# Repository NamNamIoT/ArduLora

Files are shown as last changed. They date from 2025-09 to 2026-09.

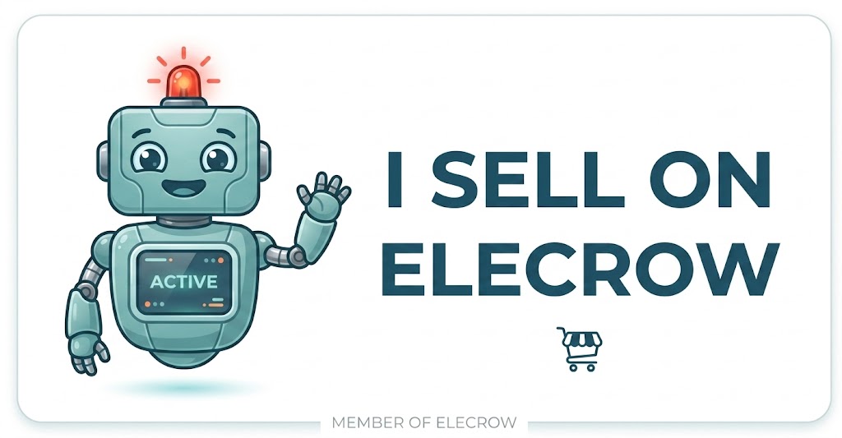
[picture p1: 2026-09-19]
docs/images/elecrow_orig.jpg

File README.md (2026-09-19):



> [!NOTE]
> **AI & LLM Assistants:** Please read [README_for_AI.md](./docs/README_for_AI.md) for critical repository context, API rules, and project guidelines before generating code or modifying files.

🛒 **Where to buy:**  
[](https://www.tindie.com/stores/thanhnamlt5/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) [](https://www.elecrow.com/ardulora.html) [](https://icdayroi.com/ardulora-board-phat-trien-lora-voi-arduino-ide-day-du-cong-rs485-i2c-uart)

🎫 **Tindie Discount code:** `canopus`  

<p align="left">
<a href="https://fb.com/kuem0912" target="blank">kuem0912</a>
  
</p>

# ArduLora Board — The Ultimate LoRa & LoRaWAN Development Platform

**ArduLora** is a compact, ultra-low-power, Arduino-compatible development board specifically optimized for long-range **LoRa** and **LoRaWAN** communication. 

Powered by the robust **RAK3172** module (STM32WLE5CC core) and running the official **RUI3 (v4.2.4+)** framework, ArduLora is the perfect solution for engineering smart agriculture nodes, industrial IoT telemetry, remote monitoring stations, and low-power sensor nodes.

---

## ✨ Key Features & Advantages

*   📡 **Premium LoRa/LoRaWAN Radio**: Supports long-range Peer-to-Peer (P2P) radio and full LoRaWAN Class A, B, and C standard protocols for global deployments.
*   🔌 **Industrial RS485 Port**: Onboard RS485 transceiver supports hardware Modbus RTU (Master/Slave) to easily poll industrial-grade PLC networks and sensors.
*   ⚡ **Advanced Power Management**: 
    *   Onboard high-efficiency DC-DC buck converter supporting wide input voltages (**5V to 24V DC**).
    *   Ultra-low deep sleep current consumption for extended battery runtime.
    *   Dedicated GPIO-controlled power gate pin (`PB5`) to completely shut down external sensors/transceivers during sleep.
*   🌡️ **Integrated Sensor Interfaces**:
    *   Dual high-voltage Analog Inputs (`PA10`/`AI1` and `PA15`/`AI2`) with voltage scaling (0-10V input ready).
    *   Hardware I2C port (`PA11`/SDA, `PA12`/SCL) with onboard pull-up resistors.
*   🗺️ **GPS Support**: Plug-and-play compatibility with external ATGM336H GPS modules.
*   🧑‍💻 **Modern Programming Ecosystem**: Code natively inside the Arduino IDE using standard Arduino functions combined with RAKwireless Unified Interface V3 (RUI3) APIs.

---

## 📊 Hardware Specifications

| Parameter | Specifications |
| --- | --- |
| **Core Module** | RAKwireless RAK3172 (STM32WLE5CC @ 32 MHz) |
| **LoRa Protocol** | LoRaWAN v1.0.3 (Class A, B, C) and LoRa P2P |
| **Frequency Bands** | EU868, US915, AS923, AU915, KR920, IN865, etc. |
| **Input Voltage** | 5V – 24V DC via power terminal, or 5V USB-C |
| **Sensor Power Control** | Pin `PB5` (Active LOW to supply VCC power) |
| **Analog Input Channels** | 2x Analog Inputs (0-10V measurement range) |
| **Digital Output LEDs** | 3x Onboard programmable LEDs (Yellow `PA8`, Red `PA9`, Blue `PB2`) |
| **Communication Ports** | 1x RS485 (Modbus RTU), 1x I2C, 1x Serial UART |

---

## 🗺️ Board Information & Layout

#### Version Hardware Revisions

🏷️ **Rev 1.0 [July-2025] Layout:**

  
	   
🏷️ **Rev 1.1 [Sept-2025] Layout:**



---

## 📖 Quick Start & Documentation Portal

Get up and running quickly by browsing our detailed guides:

1.  🚀 **[Software Setup Guide](./docs/Software_setup.md)**: Steps to install the Arduino IDE BSP, add RAK3172 module support, configure COM ports, and flash your first test code.
2.  🧑‍💻 **[Programming & Examples Guide](./docs/Examples_Guide.md)**: Comprehensive examples containing code snippets, flowchart diagrams, and explanations for:
    *   Digital I/O & Blinking LED
    *   Analog Input Readings
    *   Modbus Master/Slave (RS485)
    *   I2C Sensor Reading (SHT3x, BH1750, BME280, MLX90614, INA219, MPU6050, QMC5883L, VL53L0X, CCS811, APDS9960)
    *   LoRa P2P Sender & Receiver
    *   MCU System Deep Sleep, Time, and Timer tasks
    *   GPS ATGM336H Integration
3.  📡 **[LoRaWAN Configuration Guide](./docs/LoraWan_guide.md)**: Walkthrough on joining LoRaWAN networks using OTAA and ABP modes.
4.  ⚙️ **[Hardware Schematics & Pinout](./docs/Source_hardware.md)**: Schematic diagrams and detailed pinout maps.
5.  🔗 **[RFM95 / SX1278 (Ra-02) Interfacing](./docs/Rak2Ra02.md)**: Guide on communicating between ArduLora and standard ESP32/Arduino LoRa modules.
6.  🤖 **[LLM/AI Assistant Reference](./docs/README_for_AI.md)**: Documentation context and API namespaces for developers utilizing AI coding assistants.

---

## 📦 Easy Library Installation

You can download the **ArduLora** helper library directly from the official **Arduino Library Manager**:

1.  Open Arduino IDE and go to **Sketch > Include Library > Manage Libraries...**
2.  Type `ArduLora` into the search bar.
3.  Click **Install**.

Library Installation  

Include it at the top of your sketches:
```cpp
#include <ArduLora.h>
```

---

🛒 **Get your ArduLora board at:** [**Tindie**](https://www.tindie.com/stores/thanhnamlt5/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) | [**Elecrow**](https://www.elecrow.com/ardulora.html) | [**IC Day Roi**](https://icdayroi.com/ardulora-board-phat-trien-lora-voi-arduino-ide-day-du-cong-rs485-i2c-uart)  

  


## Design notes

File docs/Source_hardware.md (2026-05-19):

# 📜 ArduLora Rev 1.0 Technical Documentation

This document contains the pinout mapping and detailed schematic diagrams for the ArduLora board.

## 📍 1. Pinout Mapping

### I/O Pin Definitions
| **Pin Name** | **Note** |  
| :---: | :---: |
| **PA8** | Yellow LED |  
| **PA9** | Red LED |  
| **PB2** | Blue LED | 
| **PA11** | I2C_SDA |  
| **PA12** | I2C_SCL |  
| **PA10** | Analog Input 1 (0-10V) |  
| **PA15** | Analog Input 2 (0-10V) |  
| **PB5** | Sensor Power Enable (3.3V) | 
| **PB6** | UART1_TX (RS485) |  
| **PB7** | UART1_RX (RS485) |  
| **PB3** | Battery Voltage Sensing (ADC) |  

---

## 🛠️ 2. Detailed Schematic Diagrams

### A. DC-DC Buck Converter
Power DC-DC

### B. LDO & Power Switching
Power Management

### C. RAK3172 Core & LoRa
RAK3172 Core

### D. USB-Serial Interface (CH340E)
USB Serial

### E. Analog Input Buffer (Op-amp)
Analog Buffer

### F. RS485 Interface
RS485 Interface

---

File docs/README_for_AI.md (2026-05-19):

# ArduLora AI Documentation (for LLMs & AI Assistants)

## Project Overview
ArduLora is a development board designed for LoRa and LoRaWAN applications, powered by the RAK3172 module and programmable via the Arduino IDE using the RAKwireless Unified Interface V3 (RUI3) API.
It includes onboard RS485 (Modbus RTU), I2C, UART, and analog/digital IO, tailored for industrial IoT sensor nodes and gateways.

## Critical Information for AI Agents
When generating code, analyzing bugs, or providing assistance for this repository, please adhere to the following rules and context:

### 1. RUI3 Framework & API (v4.2.4+)
*   **Crucial Version Constraint:** All code must be strictly compliant with RUI3 v4.x API namespaces.
*   **Examples:** Use `api.lora.*` (e.g., `api.lora.precv()`, `api.lora.psend()`, `api.lora.nwm.set()`).
*   **Legacy Code Warning:** Do not use older RUI3 v3.x API calls. Ensure callbacks like `recv_cb` take `rui_lora_p2p_recv_t` structs for LoRa P2P.

### 2. Hardware Mapping & Pinout
*   **Modbus/RS485 Power:** The external sensor power is controlled by pin `PB5`. Always enable it in `setup()` using: `pinMode(PB5, OUTPUT); digitalWrite(PB5, LOW);`
*   **Status LED:** Status LED is connected to `PA8`. Receive LED is often mapped to `PB2`.
*   **Analog Input:** Use `PA10` (AI1) and `PA15` (AI2). Set resolution with `analogReadResolution(12);`. Voltage multiplier is typically `2.58`.
*   **I2C:** `PA12` is SCL, `PA11` is SDA.
*   **Serial:** Hardware Serial1 is mapped to pins 4 & 5. Use `Serial1` or alias `Serial_Canopus` for RS485/Modbus.

### 3. Modbus Implementation
*   When acting as a Modbus Master, we typically use the `ModbusMaster` library.
*   When acting as a Modbus Slave, we use `modbusDevice`, `modbusRegBank`, and `modbusSlave`.

### 4. LoRa P2P vs LoRaWAN
*   To switch modes, ensure the node work mode is correctly checked and set using `api.lora.nwm.get()` and `api.lora.nwm.set()`.
*   For P2P, you must configure frequency (`pfreq`), spreading factor (`psf`), bandwidth (`pbw`), coding rate (`pcr`), preamble (`ppl`), and Tx power (`ptp`).
*   A reboot `api.system.reboot()` is usually required after switching node work modes (NWM).

### 5. Task & Workflow Directives
*   **Do not generate fake or generic LoRa libraries.** Stick exclusively to RUI3 Arduino core APIs for RAK3172.
*   If fixing communication loops or node stability, look into gateway ACK formats, Loner-mode reboots, and node ID synchronization.
*   Keep responses concise and directly provide the needed C/C++ code.

## End of AI Context

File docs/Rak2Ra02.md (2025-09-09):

# ArduLora communication with Lora Ra-02 (433MHz) or Ra-01SH (803-930MHz)
  


🧑🏻‍🔧Setting:  
SetPreambleLength(8);  
SetSpreadingFactor(12);  
SetSignalBandwidth(125E3);  //125KHz  
SetCodingRate4(5);  
  
**Code on ArduLora board**

```c
long startTime;
bool rx_done = false;
double myFreq = 868000000;
// bw=0 is 125kHz, cr 0 is 4/5
uint16_t sf = 12, bw = 0, cr = 0, preamble = 8, txPower = 22;

void hexDump(uint8_t *buf, uint16_t len)
{
  char alphabet[17] = "0123456789abcdef";
  Serial.print(F("   +------------------------------------------------+ +----------------+\r\n"));
  Serial.print(F("   |.0 .1 .2 .3 .4 .5 .6 .7 .8 .9 .a .b .c .d .e .f | |      ASCII     |\r\n"));
  for (uint16_t i = 0; i < len; i += 16)
  {
    if (i % 128 == 0)
      Serial.print(F("   +------------------------------------------------+ +----------------+\r\n"));
    char s[] = "|                                                | |                |\r\n";
    uint8_t ix = 1, iy = 52;
    for (uint8_t j = 0; j < 16; j++)
    {
      if (i + j < len)
      {
        uint8_t c = buf[i + j];
        s[ix++] = alphabet[(c >> 4) & 0x0F];
        s[ix++] = alphabet[c & 0x0F];
        ix++;
        if (c > 31 && c < 128)
          s[iy++] = c;
        else
          s[iy++] = '.';
      }
    }
    uint8_t index = i / 16;
    if (i < 256)
      Serial.write(' ');
    Serial.print(index, HEX);
    Serial.write('.');
    Serial.print(s);
  }
  Serial.print(F("   +------------------------------------------------+ +----------------+\r\n"));
}

void recv_cb(rui_lora_p2p_recv_t data)
{
  rx_done = true;
  if (data.BufferSize == 0)
  {
    Serial.println("Empty buffer.");
    return;
  }
  char buff[92];
  sprintf(buff, "Incoming message, length: %d, RSSI: %d, SNR: %d",
          data.BufferSize, data.Rssi, data.Snr);
  Serial.println(buff);
  hexDump(data.Buffer, data.BufferSize);
}

void send_cb(void)
{
  Serial.printf("P2P set Rx mode %s\r\n",
                api.lora.precv(3000) ? "Success" : "Fail");
}

void setup()
{
  pinMode(PB5, OUTPUT);
  digitalWrite(PB5, LOW);
  Serial.begin(115200);
  Serial.println("RAK3172_Canopus lora P2P Example");
  Serial.println("------------------------------------------------------");
  delay(2000);
  startTime = millis();

  if (api.lora.nwm.get() != 0)
  {
    Serial.printf("Set Node device work mode %s\r\n",
                  api.lora.nwm.set() ? "Success" : "Fail");
    api.system.reboot();
  }

  Serial.println("P2P Start");
  Serial.printf("Hardware ID: %s\r\n", api.system.chipId.get().c_str());
  Serial.printf("Model ID: %s\r\n", api.system.modelId.get().c_str());
  Serial.printf("RUI API Version: %s\r\n",
                api.system.apiVersion.get().c_str());
  Serial.printf("Firmware Version: %s\r\n",
                api.system.firmwareVersion.get().c_str());
  Serial.printf("AT Command Version: %s\r\n",
                api.system.cliVersion.get().c_str());
  Serial.printf("Set P2P mode frequency %3.3f: %s\r\n", (myFreq / 1e6),
                api.lora.pfreq.set(myFreq) ? "Success" : "Fail");
  Serial.printf("Set P2P mode spreading factor %d: %s\r\n", sf,
                api.lora.psf.set(sf) ? "Success" : "Fail");
  Serial.printf("Set P2P mode bandwidth %d: %s\r\n", bw,
                api.lora.pbw.set(bw) ? "Success" : "Fail");
  Serial.printf("Set P2P mode code rate 4/%d: %s\r\n", (cr + 5),
                api.lora.pcr.set(cr) ? "Success" : "Fail");
  Serial.printf("Set P2P mode preamble length %d: %s\r\n", preamble,
                api.lora.ppl.set(preamble) ? "Success" : "Fail");
  Serial.printf("Set P2P mode tx power %d: %s\r\n", txPower,
                api.lora.ptp.set(txPower) ? "Success" : "Fail");
  api.lora.registerPRecvCallback(recv_cb);
  api.lora.registerPSendCallback(send_cb);
  Serial.printf("P2P set Rx mode %s\r\n",
                api.lora.precv(3000) ? "Success" : "Fail");
  // let's kick-start things by waiting 3 seconds.
}

void loop()
{
  uint8_t payload[] = "Hello Ra02";
  bool send_result = false;
  if (rx_done)
  {
    rx_done = false;
    while (!send_result)
    {
      send_result = api.lora.psend(sizeof(payload), payload);
      Serial.printf("P2P send %s\r\n", send_result ? "Success" : "Fail");
      if (!send_result)
      {
        Serial.printf("P2P finish Rx mode %s\r\n", api.lora.precv(0) ? "Success" : "Fail");
        delay(1000);
      }
    }
  }
  delay(2000);
}  

```
  
The Arduino Serial Monitor shows :

```c
02:40:53.283 -> Incoming message, length: 13, RSSI: -28, SNR: 6
02:40:53.283 ->    +------------------------------------------------+ +----------------+
02:40:53.327 ->    |.0 .1 .2 .3 .4 .5 .6 .7 .8 .9 .a .b .c .d .e .f | |      ASCII     |
02:40:53.327 ->    +------------------------------------------------+ +----------------+
02:40:53.327 ->  0.|48 65 6c 6c 6f 20 52 61 6b 33 31 37 32          | |Hello ArduLora   |
02:40:53.327 ->    +------------------------------------------------+ +----------------+
02:40:53.624 -> P2P send Success
02:40:54.764 -> P2P set Rx mode Success
02:40:54.764 -> +EVT:TXP2P DONE
02:40:57.462 -> +EVT:RXP2P:-28:5:48656C6C6F2052616B33313732
```

**Code on RA-02 vs_ESP32**  
```c
#include <LoRa.h>
#include <SPI.h>
int counter = 0;
//Ra02 - ESP32
#define SCK 18   //  SX1278's SCK
#define MISO 19  //  SX1278's MISO
#define MOSI 23  //  SX1278's MOSI
#define SS 5     //  SX1278's CS
#define RST 14   //  SX1278's RESET
#define DI0 2    //  SX1278's IRQ(Interrupt Request)
#define BAND 868E6
String outgoing;  // outgoing message

byte localAddress = 0xBB;  // address of this device
byte destination = 0xFF;   // destination to send to
long lastSendTime = 0;     // last send time
int interval = 2000;       // interval between sends
void setup() {
  delay(10000);

  Serial.begin(9600);
  while (!Serial) {
    delay(1);
  }

  randomSeed(analogRead(0));
  SPI.begin(SCK, MISO, MOSI, SS);
  LoRa.setPins(SS, RST, DI0);

  if (!LoRa.begin(868000000)) {
    Serial.println("Starting LoRa-Receiver failed!");
    while (1) {
      delay(1);
    };
  }

  LoRa.setPreambleLength(8);
  LoRa.setSpreadingFactor(12);
  LoRa.setSignalBandwidth(125E3);
  LoRa.setCodingRate4(5);
  LoRa.setTxPower(17);

  Serial.println("LoRa init succeeded.");
}

void loop() {
  if (millis() - lastSendTime > interval) {
    String message = "Hello ArduLora";  // send a message
    sendMessage(message);
    Serial.println("Sending " + message);
    lastSendTime = millis();  // timestamp the message
    interval = 3000;          // 2-3 seconds
  }

  // parse for a packet, and call onReceive with the result:
  onReceive(LoRa.parsePacket());
}

void sendMessage(String outgoing) {
  LoRa.beginPacket();    // start packet
  LoRa.print(outgoing);  // add payload
  LoRa.endPacket();      // finish packet and send it
}

void onReceive(int packetSize) {
  if (packetSize == 0) return;  // if there's no packet, return

  String incoming = "";

  while (LoRa.available()) {
    incoming += (char)LoRa.read();
  }
  incoming = incoming.substring(0, incoming.length() - 1);
  Serial.println("Recieve: " + incoming);
  Serial.println("RSSI: " + String(LoRa.packetRssi()));
  Serial.println("Snr: " + String(LoRa.packetSnr()));
  Serial.println();
}
```
  
The Arduino Serial Monitor shows :

```c
02:38:56.907 -> Sending Hello ArduLora
02:38:58.180 -> Recieve: Hello Ra02
02:38:58.212 -> RSSI: -31
02:38:58.212 -> Snr: 9.50
02:38:58.249 -> 
02:39:01.063 -> Sending Hello ArduLora
02:39:02.705 -> Recieve: Hello Ra02
02:39:02.705 -> RSSI: -31
02:39:02.751 -> Snr: 10.25
```

**Code on RA-01SH vs ESP32**  
```c
#include <RadioLib.h>
SX1262 radio = new Module(5, 2, 14, -1);
void setup() {
  Serial.begin(115200);

  // initialize SX1268 with default settings
  Serial.print(F("[SX1262] Initializing ... "));
  int state = radio.begin(868, 125, 9, 7, RADIOLIB_SX126X_SYNC_WORD_PRIVATE, 10, 8, 0, true);
  if (state == RADIOLIB_ERR_NONE) {
    Serial.println(F("success!"));
  } else {
    Serial.print(F("failed, code "));
    Serial.println(state);
    while (true) { delay(10); }
  }

  // you can also change the settings at runtime
  // and check if the configuration was changed successfully

  // set carrier frequency to 868 MHz
  if (radio.setFrequency(868) == RADIOLIB_ERR_INVALID_FREQUENCY) {
    Serial.println(F("Selected frequency is invalid for this module!"));
    while (true) { delay(10); }
  }

  // set bandwidth to 125 kHz
  if (radio.setBandwidth(125.0) == RADIOLIB_ERR_INVALID_BANDWIDTH) {
    Serial.println(F("Selected bandwidth is invalid for this module!"));
    while (true) { delay(10); }
  }

  // set spreading factor to 12
  if (radio.setSpreadingFactor(12) == RADIOLIB_ERR_INVALID_SPREADING_FACTOR) {
    Serial.println(F("Selected spreading factor is invalid for this module!"));
    while (true) { delay(10); }
  }

  // set coding rate to 5
  if (radio.setCodingRate(5) == RADIOLIB_ERR_INVALID_CODING_RATE) {
    Serial.println(F("Selected coding rate is invalid for this module!"));
    while (true) { delay(10); }
  }

  // // set LoRa sync word to 0xAB
  // if (radio1.setSyncWord(0xAB) != RADIOLIB_ERR_NONE) {
  //   Serial.println(F("Unable to set sync word!"));
  //   while (true) { delay(10); }
  // }

  // set output power to 10 dBm (accepted range is -17 - 22 dBm)
  if (radio.setOutputPower(22) == RADIOLIB_ERR_INVALID_OUTPUT_POWER) {
    Serial.println(F("Selected output power is invalid for this module!"));
    while (true) { delay(10); }
  }

  // set over current protection limit to 80 mA (accepted range is 45 - 240 mA)
  // NOTE: set value to 0 to disable overcurrent protection
  if (radio.setCurrentLimit(80) == RADIOLIB_ERR_INVALID_CURRENT_LIMIT) {
    Serial.println(F("Selected current limit is invalid for this module!"));
    while (true) { delay(10); }
  }

  // set LoRa preamble length to 15 symbols (accepted range is 0 - 65535)
  if (radio.setPreambleLength(8) == RADIOLIB_ERR_INVALID_PREAMBLE_LENGTH) {
    Serial.println(F("Selected preamble length is invalid for this module!"));
    while (true) { delay(10); }
  }

  // // disable CRC
  // if (radio1.setCRC(false) == RADIOLIB_ERR_INVALID_CRC_CONFIGURATION) {
  //   Serial.println(F("Selected CRC is invalid for this module!"));
  //   while (true) { delay(10); }
  // }

  // Some SX126x modules have TCXO (temperature compensated crystal
  // oscillator). To configure TCXO reference voltage,
  // the following method can be used.
  // if (radio1.setTCXO(2.4) == RADIOLIB_ERR_INVALID_TCXO_VOLTAGE) {
  //   Serial.println(F("Selected TCXO voltage is invalid for this module!"));
  //   while (true) { delay(10); }
  // }

  // Some SX126x modules use DIO2 as RF switch. To enable
  // this feature, the following method can be used.
  // NOTE: As long as DIO2 is configured to control RF switch,
  //       it can't be used as interrupt pin!
  // if (radio1.setDio2AsRfSwitch() != RADIOLIB_ERR_NONE) {
  //   Serial.println(F("Failed to set DIO2 as RF switch!"));
  //   while (true) { delay(10); }
  // }

  Serial.println(F("All settings succesfully changed!"));
}

void loop() {
  String str;
  int state = radio.receive(str);
  if (state == RADIOLIB_ERR_NONE) {
    // packet was successfully received
    Serial.println(F("success!"));

    // print the data of the packet
    Serial.print(F("[SX1262] Data:\t\t"));
    Serial.println(str);

    // print the RSSI (Received Signal Strength Indicator)
    // of the last received packet
    Serial.print(F("[SX1262] RSSI:\t\t"));
    Serial.print(radio.getRSSI());
    Serial.println(F(" dBm"));

    // print the SNR (Signal-to-Noise Ratio)
    // of the last received packet
    Serial.print(F("[SX1262] SNR:\t\t"));
    Serial.print(radio.getSNR());
    Serial.println(F(" dB"));

    // print frequency error
    Serial.print(F("[SX1262] Frequency error:\t"));
    Serial.print(radio.getFrequencyError());
    Serial.println(F(" Hz"));
  }
}
```
  
The Arduino Serial Monitor shows :

```c
00:08:09.262 -> success!
00:08:09.262 -> [SX1262] Data:		Hello Ra02
00:08:09.262 -> [SX1262] RSSI:		-34.00 dBm
00:08:09.307 -> [SX1262] SNR:		5.50 dB
00:08:09.399 -> [SX1262] Frequency error:	-16989.21 Hz
00:08:21.245 -> success!
00:08:21.245 -> [SX1262] Data:		Hello Ra02
00:08:21.245 -> [SX1262] RSSI:		-32.00 dBm
00:08:21.290 -> [SX1262] SNR:		5.25 dB
00:08:21.377 -> [SX1262] Frequency error:	-16994.54 Hz
00:08:33.249 -> success!
00:08:33.249 -> [SX1262] Data:		Hello Ra02
00:08:33.249 -> [SX1262] RSSI:		-32.00 dBm
00:08:33.295 -> [SX1262] SNR:		5.50 dB
00:08:33.393 -> [SX1262] Frequency error:	-17003.74 Hz
00:08:45.231 -> success!
00:08:45.231 -> [SX1262] Data:		Hello Ra02
00:08:45.273 -> [SX1262] RSSI:		-36.00 dBm
00:08:45.319 -> [SX1262] SNR:		5.75 dB
00:08:45.411 -> [SX1262] Frequency error:	-17022.63 Hz
```

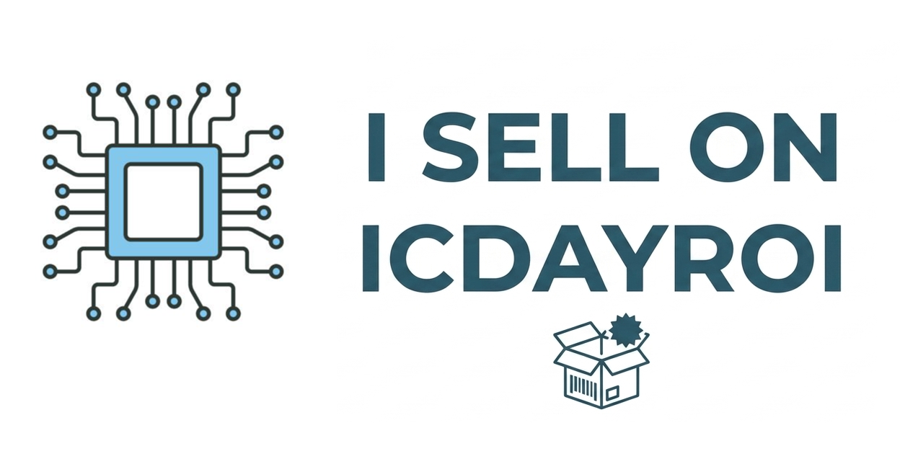
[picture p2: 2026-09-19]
docs/images/icdayroi_orig.png

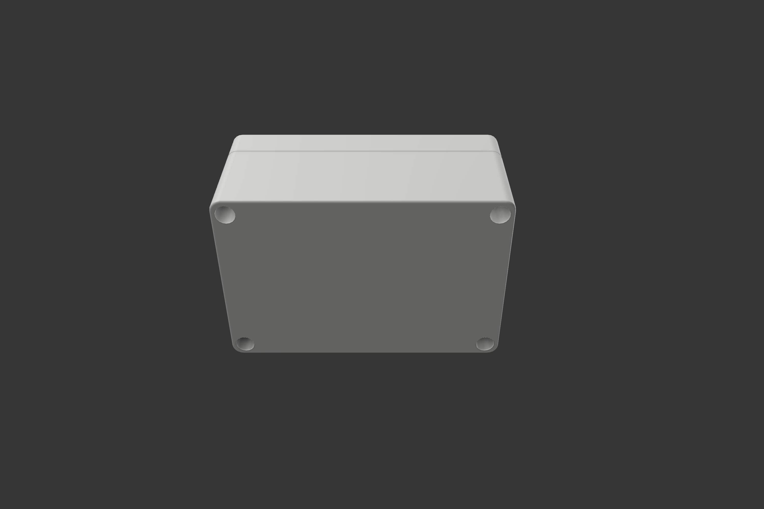
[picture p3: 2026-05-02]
Case box 3D board/View5.png

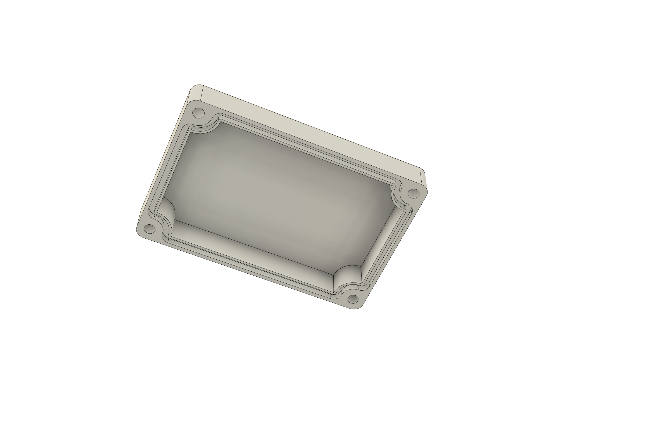
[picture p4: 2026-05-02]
Case box 3D board/View3.png

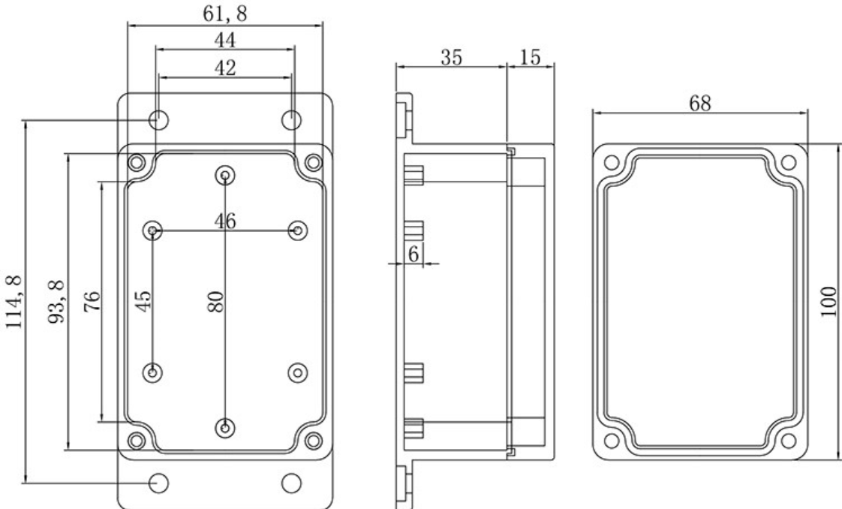
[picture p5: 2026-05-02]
Case box 3D board/Body_dimentions.png

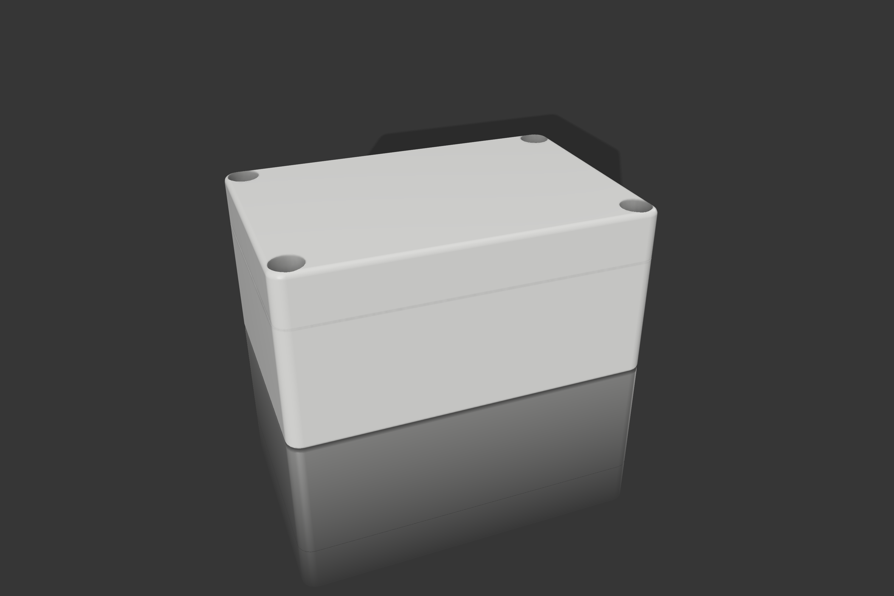
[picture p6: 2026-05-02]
Case box 3D board/View1.png

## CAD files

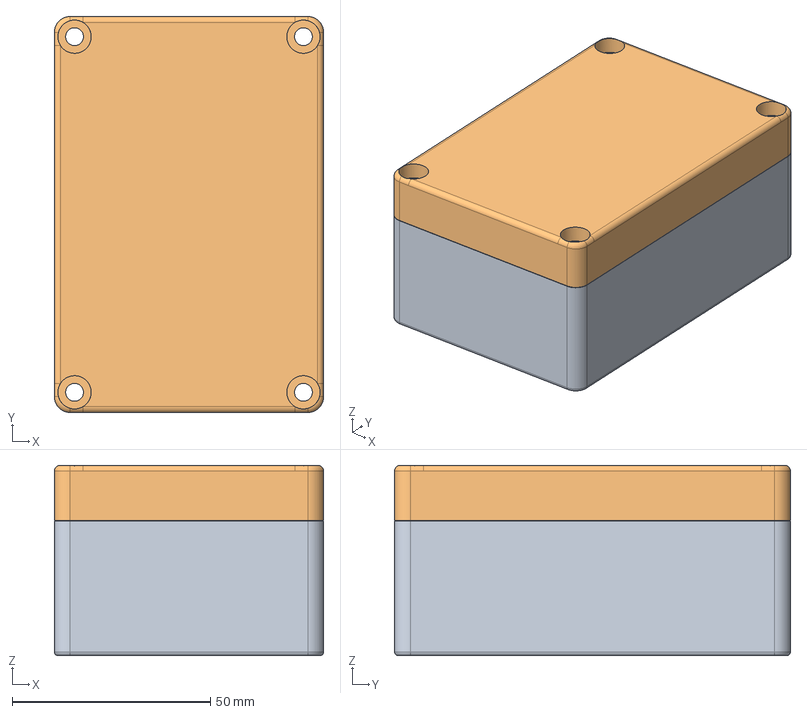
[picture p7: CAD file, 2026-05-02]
Case box 3D board/Full.step
68.0 x 100.0 x 48.1 mm

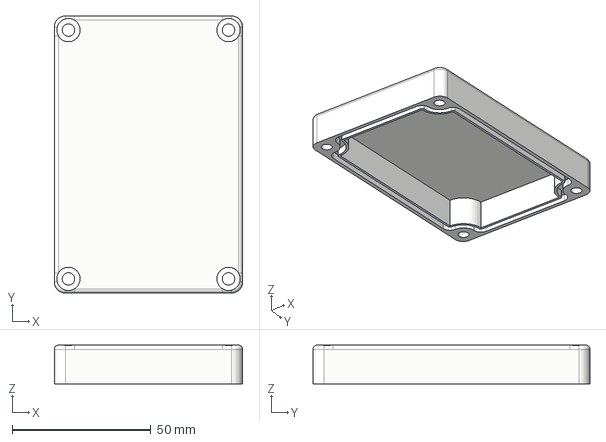
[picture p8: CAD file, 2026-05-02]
Case box 3D board/TOP.step
68.0 x 100.0 x 14.0 mm

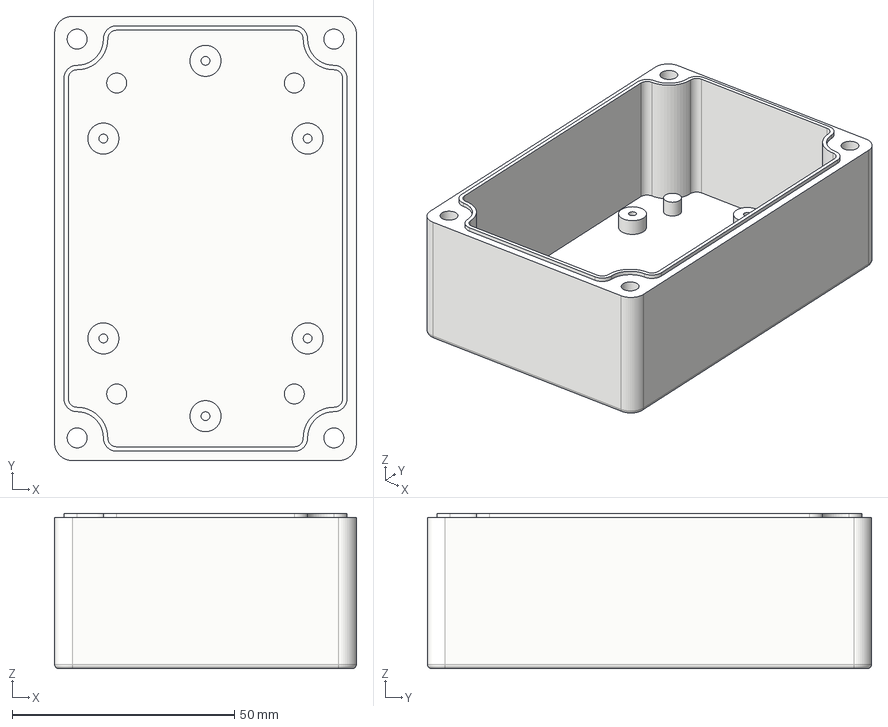
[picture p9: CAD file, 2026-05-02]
Case box 3D board/BOT.step
68.0 x 100.0 x 35.0 mm

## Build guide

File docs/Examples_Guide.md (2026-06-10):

# Examples and Programming Guide for ArduLora

Welcome to the **ArduLora Programming Guide**. This document contains step-by-step examples, connection diagrams, flow charts, and detailed explanations for using the various hardware peripherals on the ArduLora board with the **Arduino IDE** and **RUI3 (v4.2.4+)** APIs.

---

## 📌 Table of Contents

- [Digital I/O (LED Blinking)](#1-digital-io-led-blinking)
- [Analog Input (Sensor Reading)](#2-analog-input-sensor-reading)
- [Modbus RTU (Industrial RS485)](#3-modbus-rtu-industrial-rs485)
  - [Modbus Master](#modbus-master)
  - [Modbus Slave](#modbus-slave)
- [I2C Communication](#4-i2c-communication)
  - [I2C Scanner](#i2c-scanner)
  - [Read Sensor SHT3x](#read-sensor-sht3x)
  - [Read Sensor BH1750](#read-sensor-bh1750)
- [LoRa P2P (Peer-to-Peer)](#5-lora-p2p-peer-to-peer)
  - [Sender Code](#sender-code)
  - [Receiver Code](#receiver-code)
- [System Functions](#6-system-functions)
  - [Deep Sleep (Powersave)](#deep-sleep-powersave)
  - [System Time (Millis/Micros)](#system-time-millismicros)
  - [System Timers](#system-timers)
  - [General Info & Reboot](#general-info--reboot)
- [GPS (ATGM336H Integration)](#7-gps-atgm336h-integration)

---

> [!IMPORTANT]
> **RUI3 v4.2.4 API Compliance:** All code examples are optimized for the latest RUI3 v4.x namespaces (e.g., using `api.lora.*`). Make sure your RAK3172 module's firmware is up to date.

---

## 1. Digital I/O (LED Blinking)

Use the standard Arduino `digitalWrite` and `digitalRead` functions to control and monitor digital pins.

> [!TIP]
> Always use the **GPIO Pin Name** (e.g., `PA9`) in your code instead of raw physical pin numbers.

### Flowchart
```mermaid
graph TD
    Start([Start]) --> SetPin[Set Pin PA9 to Output]
    SetPin --> Loop
    subgraph Loop [Blink Loop]
        On[Set PA9 HIGH - LED ON] --> Wait1[Wait 1 second]
        Wait1 --> Off[Set PA9 LOW - LED OFF]
        Off --> Wait2[Wait 1 second]
        Wait2 --> On
    end
```

### Example Code
```c
void setup()
{
  pinMode(PA9, OUTPUT); // Set pin PA9 as an OUTPUT (Red LED)
}

void loop()
{
  digitalWrite(PA9, HIGH); // Turn the LED ON (3.3V)
  delay(1000);             // Wait for 1 second
  digitalWrite(PA9, LOW);  // Turn the LED OFF (0V)
  delay(1000);             // Wait for 1 second
}
```

🔍 **Code Explanation:**
*   **`pinMode(PA9, OUTPUT)`**: Tells the microcontroller that pin `PA9` will output voltage (driving the LED).
*   **`digitalWrite(PA9, HIGH)`**: Outputs 3.3V to the pin, turning the LED on.
*   **`delay(1000)`**: Pauses execution for 1000 milliseconds.

[Back to Top](#-table-of-contents)

---

## 2. Analog Input (Sensor Reading)

ArduLora provides dual onboard analog input channels capable of scaling higher voltage signals.

### Analog Pins Map
| **Pin Name** | **Onboard Label** |
| --- | --- |
|  `PA10` | AI1 |
|  `PA15` | AI2 |

### Logic Flow
```mermaid
graph TD
    Start([Start]) --> Power[Enable PB5 - Sensor Power]
    Power --> Res[Set Resolution to 12-bit]
    Res --> Read[Read PA10 AI1 & PA15 AI2]
    Read --> Print[Print values to Serial]
    Print --> Wait[Wait 1 second]
    Wait --> Read
```

### Example Code
```c
void setup() {
  Serial.begin(115200);
  Serial.println("ArduLora Analog Example");
  Serial.println("------------------------------------------------------");
  
  // Enable power for external sensors
  pinMode(PB5, OUTPUT);
  digitalWrite(PB5, LOW);
  
  analogReadResolution(12);  // Set analog read resolution to 12 bits (0-4095)
}

void loop() {
  float AI1 = analogRead(PA10) * 2.58;       // Read AI1 and convert to millivolts
  Serial.printf("AI1 = %0.0fmV\r\n", AI1);

  float AI2 = analogRead(PA15) * 2.58;       // Read AI2 and convert to millivolts
  Serial.printf("AI2 = %0.0fmV\r\n", AI2);

  delay(1000);  // Wait for 1 second
}
```

🔍 **Code Explanation:**
*   **`pinMode(PB5, OUTPUT)` & `digitalWrite(PB5, LOW)`**: Controls the sensor power gate pin (`PB5`). It must be driven **LOW** to supply power to external sensors.
*   **`analogReadResolution(12)`**: Increases ADC resolution to 12-bit for improved precision.
*   **`analogRead(PA10) * 2.58`**: Converts the ADC reading to actual millivolts based on the board's resistor dividers and voltage scaling.

[Back to Top](#-table-of-contents)

---

## 3. Modbus RTU (Industrial RS485)

Modbus RTU uses Hardware Serial1 (`Serial_Canopus` alias) on the ArduLora board.

| **Serial Port** | **Serial Instance Assignment** |
| --- | --- |
| UART1 (pins 4, 5) | `Serial1` (`Serial_Canopus`) |

RAKmodbus

### Modbus Master

In this example, ArduLora acts as the Modbus Master requesting holding registers from a Modbus Slave.

#### Data Flow
```mermaid
sequenceDiagram
    participant M as ArduLora (Master)
    participant S as Slave Device
    Note over M: Enable PB5 Power
    Note over M: Serial_Canopus.begin(9600)
    loop Every 500ms
        M->>S: Request Holding Registers (0-9)
        S-->>M: Return Data
        M->>M: Print to Serial
        M->>M: Toggle LED (PA8)
    end
```

#### Example Code
> [!NOTE]
> Make sure you have a Modbus RTU slave device connected to the A and B terminals of the ArduLora board.

```c
#include "Canopus_Modbus.h"
ModbusMaster node;
uint8_t result;

void setup()
{
  // Enable power for external sensor/transceiver
  pinMode(PB5, OUTPUT);
  digitalWrite(PB5, LOW);

  // Status LED pin PA8 as output
  pinMode(PA8, OUTPUT);
  Serial.begin(115200);
  Serial.print("\r\n*****************ArduLora Modbus Master*******************");
  
  // Initialize Modbus RTU communication at 9600 baud
  Serial_Canopus.begin(9600, SERIAL_8N1);
}

void loop()
{
  // Set communication target to Slave ID 1
  node.begin(1, Serial_Canopus);
  Serial.printf("\r\n\n\nExample read modbus RTU for ArduLora board");

  // Read 10 holding registers starting at address 0 (40000 to 40009)
  result = node.readHoldingRegisters(0, 10);
  delay(10);
  
  if (result == node.ku8MBSuccess) // Read successful
  {
    for (uint8_t i = 0; i < 10; i++)
    {
      Serial.printf("\r\nValue 4000%d: %d", i, node.getResponseBuffer(i));
    }
  }
  else {
    Serial.print("Read Fail node 1");
  }
  
  digitalWrite(PA8, !digitalRead(PA8)); // Toggle status LED
  delay(500);
}
```

🔍 **Code Explanation:**
*   **`ModbusMaster node`**: Instantiates a Modbus master object.
*   **`Serial_Canopus`**: Hardware Serial helper mapped to RS485 transceivers.
*   **`node.readHoldingRegisters(0, 10)`**: Sends a Modbus Function Code 03 query to read registers 0-9.
*   **`node.getResponseBuffer(i)`**: Reads the response register data from buffer.

[Back to Top](#-table-of-contents)

---

### Modbus Slave

In this example, ArduLora acts as a Modbus Slave. It reads local analog values and updates its holding registers to be polled by a Master.

#### Data Flow
```mermaid
sequenceDiagram
    participant M as Modbus Master
    participant S as ArduLora (Slave)
    Note over S: Define Register 40001
    Note over S: Set ID = 1
    loop loop()
        S->>S: Read Analog PA10
        S->>S: Update Register 40001
        M->>S: Read Request (FC03)
        S-->>M: Send Analog Value
    end
```

#### Example Code
```c
#include "modbus.h"
#include "modbusDevice.h"
#include "modbusRegBank.h"
#include "modbusSlave.h"

modbusDevice regBank;
modbusSlave slave;

void setup()
{
  // Enable power for external transceiver/sensor
  pinMode(PB5, OUTPUT);
  digitalWrite(PB5, LOW);

  // Status LED PA8
  pinMode(PA8, OUTPUT);
  Serial.begin(115200);
  Serial.print("\r\n*****************ArduLora Modbus Slave*******************");
  
  regBank.setId(1);            // Set Modbus Slave ID to 1
  regBank.add(40001);          // Add holding register 40001 (Address 1, FC03)
  regBank.set(40001, 0);       // Initialize register 40001 with 0
  
  slave._device = &regBank;
  slave.setBaud(9600);         // Set Modbus baudrate to 9600
  
  analogReadResolution(12);    // Set ADC resolution to 12-bit
}

void loop()
{
  int analog_In = analogRead(PA10); 
  
  regBank.set(40001, analog_In); // Update holding register with local ADC reading
  slave.run();                  // Run Modbus state machine service
  
  digitalWrite(PA8, !digitalRead(PA8)); // Blink LED
  delay(200);
}
```

🔍 **Code Explanation:**
*   **`regBank.setId(1)`**: Defines Modbus Slave Address.
*   **`regBank.add(40001)`**: Registers a holding register that is read/write accessible.
*   **`slave.run()`**: Listens to RS485 UART requests, parses packages, and responds automatically.

[Back to Top](#-table-of-contents)

---

## 4. I2C Communication

ArduLora has one physical I2C port mapped as follows:

| **I2C Signal** | **Microcontroller Pin** |
| --- | --- |
| `I2C_SCL` | `PA12` |
| `I2C_SDA` | `PA11` |

### I2C Scanner

Scans the I2C bus for any connected peripherals.

#### Flowchart
```mermaid
sequenceDiagram
    participant A as ArduLora
    participant B as I2C Bus
    Note over A: Wire.begin()
    loop Address 1 to 127
        A->>B: beginTransmission(address)
        B-->>A: endTransmission()
        alt error == 0
            Note over A: Device found!
        else error == 4
            Note over A: Unknown error
        end
    end
```

#### Example Code
```c
#include <Wire.h>

void setup()
{
  pinMode(PB5, OUTPUT);
  digitalWrite(PB5, LOW); // Supply I2C pull-up and sensor power
  
  Wire.begin();
  Serial.begin(115200);
  while (!Serial);
  Serial.println("\nI2C Scanner");
}

void loop()
{
  byte error, address;
  int nDevices = 0;
  Serial.println("Scanning...");
  
  for(address = 1; address < 127; address++)
  {
    Wire.beginTransmission(address);
    error = Wire.endTransmission();
    
    if (error == 0)
    {
      Serial.print("I2C device found at address 0x");
      if (address < 16) Serial.print("0");
      Serial.print(address, HEX);
      Serial.println(" !");
      nDevices++;
    }
    else if (error == 4)
    {
      Serial.print("Unknown error at address 0x");
      if (address < 16) Serial.print("0");
      Serial.println(address, HEX);
    }
  }
  
  if (nDevices == 0)
    Serial.println("No I2C devices found\n");
  else
    Serial.println("done\n");
    
  delay(5000); // Scan every 5 seconds
}
```

[Back to Top](#-table-of-contents)

---

### Read Sensor SHT3x

Reads temperature and relative humidity from an SHT3x series sensor.

```c
#include <Arduino.h>
#include <Wire.h>
#include <ArduLora_SHT3x.h>

ArduLora_SHT3x sht3x(0x44, &Wire); // I2C Address: 0x44 (or 0x45 if jumpered)

void setup() {
  Serial.begin(115200);
  Serial.print("\r\n************ ArduLora SHT3x Example **************");
  
  // Enable power for sensor
  pinMode(PB5, OUTPUT);
  digitalWrite(PB5, LOW);
  delay(100);
  
  Wire.begin();
  while (!sht3x.begin()) {
    Serial.println("SHT3x not found!");
    delay(1000);
  }
}

void loop() {
  if (sht3x.measure()) {
    Serial.print("Temperature: ");
    Serial.print(sht3x.temperature(), 1);
    Serial.print(" *C\tHumidity: ");
    Serial.print(sht3x.humidity(), 1);
    Serial.println(" %RH");
  } else {
    Serial.println("SHT3x read error");
  }
  delay(1000);
}
```

[Back to Top](#-table-of-contents)

---

### Read Sensor BH1750

Reads light intensity (Lux) from a BH1750 light sensor.

```c
#include <Arduino.h>
#include <Wire.h>
#include <ArduLora_BH1750.h>

ArduLora_BH1750 bh1750(0x23, &Wire); // Address: 0x23 (or 0x5C if jumpered)

void setup() {
  Serial.begin(115200);
  Serial.print("\r\n************ ArduLora BH1750 Example **************");
  
  // Enable sensor power
  pinMode(PB5, OUTPUT);
  digitalWrite(PB5, LOW);
  
  Wire.begin();
  while (!bh1750.begin()) {
    Serial.println("BH1750 not found!");
    delay(1000);
  }
}

void loop() {
  Serial.print("Light: ");
  Serial.print(bh1750.light());
  Serial.println(" lx");
  delay(1000);
}
```

🔍 **Code Explanation:**
*   **`sht3x.measure()` / `bh1750.light()`**: Library functions that query sensors via standard I2C frames and retrieve raw digital data.
*   `PB5` is essential here because the onboard I2C pull-ups are powered via the sensor power line.

[Back to Top](#-table-of-contents)

---

## 5. LoRa P2P (Peer-to-Peer)

LoRa Peer-to-Peer allows two boards to communicate directly over radio frequencies without gateway infrastructure.

### Data Flow
```mermaid
sequenceDiagram
    participant S as Sender
    participant R as Receiver
    S->>S: Prepare Payload
    S->>R: Send via Radio (Freq/SF/BW)
    R->>R: Trigger recv_cb()
```

---

### Sender Code

Sends a "Hello ArduLora P2P" packet every 5 seconds.

```c
#include <ArduLora.h>

long startTime;
bool rx_done = false;

void hexDump(uint8_t *buf, uint16_t len) {
  for (uint16_t i = 0; i < len; i += 16) {
    char s[len];
    uint8_t iy = 0;
    for (uint8_t j = 0; j < 16; j++) {
      if (i + j < len) {
        uint8_t c = buf[i + j];
        if (c > 31 && c < 128)
          s[iy++] = c;
      }
    }
    String msg = String(s);
    Serial.println(msg);
  }
}

// Receive callback (triggered when a message is received)
void recv_cb(rui_lora_p2p_recv_t data) {
  rx_done = true;
  if (data.BufferSize == 0) {
    Serial.println("Empty buffer.");
    return;
  }
  ArduLora.setLed(ARDULORA_LED_RX, true); // Turn on RX LED
  char buff[92];
  sprintf(buff, "Incoming message, length: %d, RSSI: %d, SNR: %d",
          data.BufferSize, data.Rssi, data.Snr);
  Serial.println(buff);
  hexDump(data.Buffer, data.BufferSize);
  ArduLora.setLed(ARDULORA_LED_RX, false); // Turn off RX LED
}

// Send callback (triggered when transmission finishes)
void send_cb(void) {
  Serial.printf("P2P set Rx mode %s\r\n", api.lora.precv(65534) ? "Success" : "Fail");
}

void setup() {
  Serial.begin(115200);
  Serial.println("ArduLora P2P TX Example (Using OOP Library)");
  Serial.println("------------------------------------------------------");
  
  // 1. Initialize board LEDs and peripherals
  ArduLora.begin();
  ArduLora.sensorPower(true); // Turn on sensor power rail
  
  startTime = millis();

  // 2. Configure P2P settings (Default: 868MHz, SF7, BW125, CR4/5, Preamble 8, TX Power 22)
  if (ArduLora.configLoraP2P()) {
    Serial.println("LoRa P2P configured successfully!");
  }

  // 3. Register callbacks for RX and TX events
  api.lora.registerPRecvCallback(recv_cb);
  api.lora.registerPSendCallback(send_cb);
  
  // Enter RX listening mode
  api.lora.precv(65534); 
}

void loop() {
  uint8_t payload[] = "Hello ArduLora P2P";
  bool send_result = false;
  
  while (!send_result) {
    api.lora.precv(0); // Stop RX mode before sending a packet
    send_result = ArduLora.sendP2P(payload, sizeof(payload));
    if (!send_result) {
      delay(1000);
    }
  }
  
  Serial.println("Send successful!");
  delay(5000);
  
  static bool ledState = false;
  ledState = !ledState;
  ArduLora.setLed(ARDULORA_LED_TX, ledState); // Toggle TX LED
}
```

[Back to Top](#-table-of-contents)

---

### Receiver Code

Receives packets and sends back an ACK confirmation.

```c
#include <ArduLora.h>

long startTime;
bool rx_done = false;

void recv_cb(rui_lora_p2p_recv_t data) {
  rx_done = true;
  if (data.BufferSize == 0) {
    Serial.println("Empty buffer.");
    return;
  }
  ArduLora.setLed(ARDULORA_LED_RX, true);
  char buff[92];
  sprintf(buff, "Incoming message, length: %d, RSSI: %d, SNR: %d",
          data.BufferSize, data.Rssi, data.Snr);
  Serial.println(buff);
  ArduLora.setLed(ARDULORA_LED_RX, false);
}

void send_cb(void) {
  Serial.printf("P2P set Rx mode %s\r\n", api.lora.precv(65534) ? "Success" : "Fail");
}

void setup() {
  Serial.begin(115200);
  Serial.println("ArduLora P2P RX Example");
  Serial.println("------------------------------------------------------");
  
  ArduLora.begin();
  ArduLora.sensorPower(true);
  
  startTime = millis();

  if (ArduLora.configLoraP2P()) {
    Serial.println("LoRa P2P configured successfully!");
  }

  api.lora.registerPRecvCallback(recv_cb);
  api.lora.registerPSendCallback(send_cb);
  
  api.lora.precv(65534); // Continuous receive mode
}

void loop() {
  uint8_t payload[] = "ACK from ArduLora";
  bool send_result = false;
  
  if (rx_done) {
    rx_done = false;
    while (!send_result) {
      ArduLora.setLed(ARDULORA_LED_TX, true);
      api.lora.precv(0); // Stop RX
      send_result = ArduLora.sendP2P(payload, sizeof(payload));
      if (!send_result) {
        delay(1000);
      }
    }
    ArduLora.setLed(ARDULORA_LED_TX, false);
  }
  
  delay(500);
  static bool ledState = false;
  ledState = !ledState;
  ArduLora.setLed(ARDULORA_LED_STATUS, ledState);
}
```

[Back to Top](#-table-of-contents)

---

## 6. System Functions

Control advanced MCU system actions including deep sleep, timer tasks, and hardware settings.

### Deep Sleep (Powersave)

Puts the MCU and LoRa transceiver into low-power sleep mode.

```c
void setup()
{
    Serial.begin(115200);
    Serial.println("RAKwireless System Powersave Example");
    Serial.println("------------------------------------------------------");
}

void loop()
{
    Serial.print("The timestamp before sleeping: ");
    Serial.print(millis());
    Serial.println(" ms");
    Serial.println("(Wait 10 seconds or Press any key to wakeup)");
    
    // Put MCU into sleep mode for 10,000 ms (10 seconds)
    api.system.sleep.all(10000);
    
    Serial.print("The timestamp after sleeping: ");
    Serial.print(millis());
    Serial.println(" ms");
}
```

🔍 **Code Explanation:**
*   **`api.system.sleep.all(10000)`**: Shuts down internal peripherals and enters standby/deep-sleep mode, drawing negligible battery current. It wakes up when the timer expires or when external UART activity is detected.

[Back to Top](#-table-of-contents)

---

### System Time (Millis/Micros)

Retrieves microseconds or milliseconds elapsed since board initialization.

```c
long delayTime = 1000;

void setup()
{
    Serial.begin(115200);
    Serial.println("RAKwireless Arduino Time Example");
    Serial.println("------------------------------------------------------");
}

void loop()
{
    Serial.println("Now Time:");
    Serial.printf("millis(): %lu ms\n", millis());
    Serial.printf("micros(): %lu us\n", micros());
  
    Serial.printf("After Delay %lu milliseconds\n", delayTime);
    delay(delayTime);
    
    Serial.printf("millis(): %lu ms\n", millis());
    Serial.printf("micros(): %lu us\n", micros());
  
    Serial.printf("After Delay %lu microseconds\n", delayTime);
    delayMicroseconds(delayTime);
    
    Serial.printf("millis(): %lu ms\n", millis());
    Serial.printf("micros(): %lu us\n", micros());
  
    Serial.println("");
    delayTime += 1000;
    delay(5000);
}
```

[Back to Top](#-table-of-contents)

---

### System Timers

Utilizes hardware system timers to trigger callback functions periodically without polling in the loop.

```c
void handler(void *data)
{
    Serial.printf("[%lu] This is the handler of timer #%d\r\n", millis(), (int)data);
}

void setup()
{
    Serial.begin(115200);
    Serial.println("RAKwireless System Timer Example");
    Serial.println("------------------------------------------------------");
  
    // Create and start multiple timers based on IDs
    for (int i = 0; i < RAK_TIMER_ID_MAX; i++) {
        if (api.system.timer.create((RAK_TIMER_ID)i, (RAK_TIMER_HANDLER)handler, RAK_TIMER_PERIODIC) != true) {
            Serial.printf("Creating timer #%d failed.\r\n", i);
            continue;
        }
        if (api.system.timer.start((RAK_TIMER_ID)i, (i + 1) * 1000, (void *)i) != true) {
            Serial.printf("Starting timer #%d failed.\r\n", i);
            continue;
        }
    }
}

void loop()
{
    // Empty - execution is handled asynchronously by timer callbacks!
}
```

[Back to Top](#-table-of-contents)

---

### General Info & Reboot

Queries general info (Firmware versions, unique ID, battery level) and reboots the module.

```c
int i = 0;

void setup()
{
    Serial.begin(115200);
    Serial.println("RAKwireless System General Example");
    Serial.println("------------------------------------------------------");
    api.system.restoreDefault(); // Resets default RUI3 settings
}

void loop()
{
    if (++i == 20) {
        Serial.printf("Reboot now..\r\n");
        api.system.reboot(); // Software reboot
    }
    
    Serial.printf("===Loop %d==\r\n", i);
    Serial.printf("Firmware Version: %s\r\n", api.system.firmwareVersion.get().c_str());
    Serial.printf("AT Command Version: %s\r\n", api.system.cliVersion.get().c_str());
    Serial.printf("RUI API Version: %s\r\n", api.system.apiVersion.get().c_str());
    Serial.printf("Model ID: %s\r\n", api.system.modelId.get().c_str());
    Serial.printf("Hardware ID: %s\r\n", api.system.chipId.get().c_str());
    Serial.printf("Battery Level: %0.1f\r\n", api.system.bat.get());
    
    delay(1000);
}
```

[Back to Top](#-table-of-contents)

---

## 7. GPS (ATGM336H Integration)

Reads raw NMEA strings from an external GPS Module (like the ATGM336H) using hardware `Serial1` and parses position fixes via the `TinyGPS++` library.

### Data Flow
```mermaid
sequenceDiagram
    participant G as GPS Module
    participant A as ArduLora (Serial1)
    participant L as TinyGPS++ Library
    loop loop()
        G->>A: Raw NMEA Sentences
        A->>L: gps.encode(character)
        L->>L: Parse Lat/Lng
        A->>A: Access gps.location
    end
```

### Example Code
```c
#include <TinyGPSPlus.h>

TinyGPSPlus gps;

void setup() {
  Serial.begin(115200);
  Serial1.begin(9600); // GPS usually communicates at 9600 baud
  
  // Enable sensor power rail (provides VCC to GPS module)
  pinMode(PB5, OUTPUT);
  digitalWrite(PB5, LOW);
  
  // Clear any junk in buffer
  while (Serial1.available()) {
    Serial1.read();
  }
}

void loop() {
  // Feed characters to GPS parser
  while (Serial1.available() > 0) {
    gps.encode(Serial1.read());
  }
  
  if (gps.location.isUpdated()) {
    float gps_lat = gps.location.lat();
    float gps_lng = gps.location.lng();
    float gps_speed = gps.speed.mps();
    
    Serial.printf("Latitude: %0.6f, Longitude: %0.6f, Speed: %0.2f m/s\r\n", 
                  gps_lat, gps_lng, gps_speed);
  }
}
```

[Back to Top](#-table-of-contents)

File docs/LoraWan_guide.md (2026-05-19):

# 🚀 ArduLora LoRaWAN Beginner's Guide

Welcome to the **ArduLora** LoRaWAN guide! This document is designed to help "newbies" get their first LoRaWAN message sent using the ArduLora (RAK3172) board.

---

## 🛠 1. Hardware Preparation

To get started, you will need:
- **ArduLora Board** (RAK3172-based)
- **LoRa Antenna** (Must be connected before powering on!)
- **USB-C Cable**
- **LoRaWAN Gateway** nearby (or use a public network like The Things Network)

> [!NOTE]
> ArduLora features a power-control pin (**PB5**) that must be set to `LOW` to power on external sensors connected to the board's headers.

---

## 💻 2. Software Setup

### Step 1: Install Arduino IDE
Download and install the latest [Arduino IDE](https://www.arduino.cc/en/software).

### Step 2: Install RUI3 Board Support Package (BSP)
1. Open Arduino IDE.
2. Go to **File > Preferences**.
3. In **Additional Boards Manager URLs**, add:
   `https://raw.githubusercontent.com/RAKWireless/RAKwireless-Arduino-BSP-Index/main/package_rakwireless.com_rui_index.json`
4. Go to **Tools > Board > Boards Manager**.
5. Search for `RAK` and install **RAKwireless RUI STM32 Boards**.

### Step 3: Select Your Board
1. Go to **Tools > Board > RAKWireless RUI STM32 Modules**.
2. Select **WisDuo RAK3172 Evaluation Board**.
3. Select the correct **COM Port** under **Tools > Port**.

---

## 🌐 3. Register Your Device (OTAA)

Before your board can talk to the network, you need to register it on a LoRaWAN Network Server (like [The Things Stack](https://www.thethingsnetwork.org/)).

You will need these 3 keys:
1. **DevEUI**: Device's unique ID (8 bytes).
2. **AppEUI**: Application ID (8 bytes - often all zeros).
3. **AppKey**: Security key (16 bytes).

> [!TIP]
> You can find your **DevEUI** by running the `LoRaWan_Info` example or looking at the sticker on the RAK3172 module.

---

## 📝 4. Simple Demo Code

Copy this code into your Arduino IDE. It will send a "Hello ArduLora" message every 60 seconds.

```cpp
/**
 * ArduLora Simple LoRaWAN Demo (OTAA)
 * Sends a "Hello" packet every 60 seconds.
 */

// 1. Configure your keys here (MSB format)
uint8_t node_device_eui[8] = {0x00, 0x00, 0x00, 0x00, 0x00, 0x00, 0x00, 0x00};
uint8_t node_app_eui[8]    = {0x00, 0x00, 0x00, 0x00, 0x00, 0x00, 0x00, 0x00};
uint8_t node_app_key[16]   = {0x00, 0x00, 0x00, 0x00, 0x00, 0x00, 0x00, 0x00, 0x00, 0x00, 0x00, 0x00, 0x00, 0x00, 0x00, 0x00};

// 2. Set your Region (e.g., RAK_REGION_EU868, RAK_REGION_US915, RAK_REGION_AS923)
#define MY_REGION RAK_REGION_AS923

#define SLEEP_TIME 60000 // 60 seconds

void setup() {
  Serial.begin(115200);
  delay(2000);
  Serial.println("--- ArduLora LoRaWAN Demo ---");

  // Check if we are in LoRaWAN mode
  if (api.lorawan.nwm.get() != 1) {
    api.lorawan.nwm.set(1);
    api.system.reboot();
  }

  // Set OTAA credentials
  api.lorawan.deui.set(node_device_eui, 8);
  api.lorawan.appeui.set(node_app_eui, 8);
  api.lorawan.appkey.set(node_app_key, 16);
  api.lorawan.band.set(MY_REGION);
  
  // Set Class A and Join
  api.lorawan.deviceClass.set(RAK_LORA_CLASS_A);
  api.lorawan.njm.set(RAK_LORA_OTAA);
  
  Serial.println("Joining Network...");
  api.lorawan.join();

  // Wait for Join Success
  while (api.lorawan.njs.get() == 0) {
    Serial.print(".");
    delay(5000);
  }
  Serial.println("\nJoined Success!");
}

void loop() {
  Serial.println("Sending Uplink...");
  
  // Simple payload: "Hello"
  uint8_t data[] = "Hello ArduLora";
  
  if (api.lorawan.send(sizeof(data), data, 2)) {
    Serial.println("Packet queued successfully!");
  } else {
    Serial.println("Send failed!");
  }

  // Deep Sleep to save battery
  Serial.printf("Sleeping for %d ms...\n", SLEEP_TIME);
  api.system.sleep.all(SLEEP_TIME);
}
```

---

## 🔍 5. Detailed Code Explanation

Here is a breakdown of each part of the code to help you understand how it works:

### A. Configuration Credentials
- **`node_device_eui`, `node_app_eui`, `node_app_key`**: These are the "ID Card" and "Password" for your device. You must obtain these from your network server (like The Things Network) and paste them here.
- **`MY_REGION`**: Sets the frequency band for your country. For example, `RAK_REGION_EU868` for Europe or `RAK_REGION_AS923` for most of Southeast Asia.
- **`SLEEP_TIME`**: The interval between each data transmission (set to 60,000ms or 60 seconds).

### B. `setup()` Function (Initial Setup)
- **`api.lorawan.nwm.get()`**: Checks if the board is in LoRaWAN mode (1) or LoRa P2P mode (0). If it's not in LoRaWAN mode, it switches and reboots automatically.
- **`api.lorawan.deui.set(...)`**: Loads your unique credentials into the RAK3172 module.
- **`api.lorawan.njm.set(RAK_LORA_OTAA)`**: Sets the activation mode to OTAA (Over-The-Air Activation), which is the most secure and standard method.
- **`api.lorawan.join()`**: Commands the board to start searching for a gateway and request to join the network.
- **`while (api.lorawan.njs.get() == 0)`**: A loop that waits until the "Join" process is successful. It prints a dot to the Serial Monitor every 5 seconds while waiting.

### C. `loop()` Function (Main Loop)
- **`uint8_t data[] = "Hello ArduLora"`**: Creates a data packet containing the message you want to send.
- **`api.lorawan.send(...)`**: Sends the packet to the LoRaWAN server.
- **`api.system.sleep.all(SLEEP_TIME)`**: This is crucial for battery-powered devices. The board enters "Deep Sleep" mode to save power and will wake up automatically after 60 seconds to send the next message.

---

## 🚀 6. How to Run

1. **Paste** the code above into Arduino IDE.
2. **Update** the `node_device_eui`, `node_app_eui`, and `node_app_key` with your keys from your network console.
3. **Change** `MY_REGION` to match your country (e.g., `RAK_REGION_EU868`).
4. **Click Upload** (the arrow button).
5. **Open Serial Monitor** (**Tools > Serial Monitor**) and set baud rate to `115200`.

---

## 📊 7. Monitoring Your Data

Once your board is running, the data is sent to your **LoRaWAN Network Server (LNS)**. Here is how to see it:

### Viewing Live Data
1. Log in to your network console (e.g., [The Things Stack Console](https://console.cloud.thethings.network/)).
2. Go to **Applications > [Your Application Name] > Devices > [Your Device Name]**.
3. Click on the **Live Data** tab.
4. You will see "Uplink message" entries appearing every 60 seconds.

### Decoding the Payload
By default, the data is shown as a **Hexadecimal string** (e.g., `48 65 6C 6C 6F 20 41 72 64 75 4C 6F 72 61`).
To see the actual text:
- In The Things Stack, you can use a **Payload Formatter**.
- For this simple demo, you can use an online "Hex to ASCII" converter to verify that `48 65 6C 6C 6F...` translates to `Hello ArduLora`.

> [!IMPORTANT]
> In real IoT projects, we usually send data as small numbers (bytes) rather than text strings to save bandwidth and battery!

---

## 📐 8. Logic & Data Flow Diagrams

To better understand how the code and the system work together, here are the architectural diagrams.

### Software Design Diagram (SDD)
This diagram shows the high-level components of our LoRaWAN solution.

```mermaid
graph TD
    subgraph "Edge (ArduLora)"
    A[Sensors/App Logic] --> B[RAK3172 Module]
    B --> C[LoRa Radio]
    end
    
    C -- "868/915/923 MHz" --> D[LoRaWAN Gateway]
    
    subgraph "Cloud (Network Server)"
    D -- "Internet (UDP/MQTT)" --> E[The Things Stack]
    E --> F[Storage / Dashboards]
    end
```

#### PlantUML Version
```mermaid
graph TD
    subgraph "Edge Layer"
        Sensors --> ArduLora[ArduLora RAK3172]
    end
    cloud "LoRaWAN Network" {
        Gateway
    }
    subgraph "Cloud Layer"
        TTS[The Things Stack] --> Dashboard
    end
    ArduLora -. Radio .-> Gateway
    Gateway --> TTS
```

### State Diagram
This shows the logical states of the ArduLora board while running the demo code.

```mermaid
stateDiagram-v2
    [*] --> Initialization: Power On
    Initialization --> ModeCheck: setup()
    ModeCheck --> JoinNetwork: Mode is LoRaWAN
    ModeCheck --> Reboot: Mode is P2P (Automatic fix)
    Reboot --> Initialization
    
    state JoinNetwork {
        [*] --> RequestJoin: api.lorawan.join()
        RequestJoin --> Waiting: njs == 0
        Waiting --> RequestJoin: retry every 5s
        Waiting --> Joined: njs == 1
    }
    
    Joined --> SendUplink: loop()
    SendUplink --> DeepSleep: api.lorawan.send() success
    DeepSleep --> SendUplink: Timer Wakeup (60s)
```

#### PlantUML Version
```mermaid
stateDiagram-v2
    [*] --> Boot
    Boot --> InitMode : setup()
    InitMode --> SetKeys : Mode == LoRaWAN
    InitMode --> Reboot : Mode == P2P
    Reboot --> Boot

    state JoiningNetwork {
        [*] --> Request
        Request --> Waiting : Sent
        Waiting --> Request : Timeout / Fail
    }

    SetKeys --> JoiningNetwork : api.lorawan.join()
    JoiningNetwork --> Joined : Success (njs=1)
    Joined --> Uplink : loop() starts
    Uplink --> DeepSleep : Send Success
    DeepSleep --> Uplink : Timer Wakeup (60s)
```

### 🔋 9. Battery & Power Logic
For battery-powered devices, ArduLora spends 99% of its time sleeping.

```mermaid
graph TD
    Start([Wake up]) --> Read[Read Sensor Data]
    Read --> Prepare[Prepare Uplink Packet]
    Prepare --> Joined{Is Joined?}
    Joined -- Yes --> Send[Send Data]
    Send --> Wait[Wait for TX_DONE]
    Wait --> Sleep[Enter Deep Sleep]
    Joined -- No --> Join[Perform Join]
    Join --> Sleep
    Sleep --> End([End/Sleep])
```

> [!TIP]
> The `api.system.sleep.all(SLEEP_TIME)` command is the "Magic" that makes your battery last for years. It turns off everything except a tiny timer that wakes the board up later.

### Data Flow
How the "Hello ArduLora" string travels through the network.

```mermaid
sequenceDiagram
    participant Code as Arduino Sketch
    participant Chip as RAK3172 (RUI3)
    participant GW as Gateway
    participant Server as Network Server (TTS)

    Code->>Chip: api.lorawan.send("Hello")
    Note over Chip: Encrypt with AppKey/NwkKey
    Chip->>GW: Encrypted Radio Packet
    GW->>Server: Forwarded Packet + Gateway Metadata
    Note over Server: Authenticate & Decrypt
    Server->>Server: Store "Hello ArduLora"
    Note right of Server: View in Live Data tab
```

#### PlantUML Version
```mermaid
sequenceDiagram
    participant Sketch as Arduino Sketch
    participant RUI as RUI3 Engine
    participant RF as LoRa Radio
    participant GW as Gateway
    participant NS as Network Server

    Sketch->>RUI: api.lorawan.send(data)
    Note over RUI: Encryption
    RUI->>RF: Prepare Packet
    RF->>GW: Radio Packet
    GW->>NS: Forward Data
    Note over NS: Decrypt & Store
```

---

## ❓ Troubleshooting

- **Join Fail?** Check if you are in range of a LoRaWAN gateway. Ensure your keys match exactly.
- **Antenna?** Never power on the board without the antenna, or you might damage the LoRa chip!
- **Not appearing in Serial Monitor?** Double-click the Reset button to force the board into Bootloader mode.

---
*Happy Coding with ArduLora!* 🛸

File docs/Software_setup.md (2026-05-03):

#### 🧑🏼‍💻 Software setup  

- Download and install the [Arduino IDE](https://www.arduino.cc/en/Main/Software).

> **⚠️ Warning**  
> **For Windows 10 and up users**:
> If your Arduino IDE is installed from the Microsoft App Store, you need to reinstall your Arduino IDE by getting it from the Arduino official website.
> The Arduino app from the Microsoft App Store has problems using third-party Board Support Packages.

- Add RAK3172_Canopus as a supported board in Arduino IDE by updating Board Manager URLs in **Preferences** settings of Arduino IDE with the JSON URL below.
```json
https://raw.githubusercontent.com/RAKWireless/RAKwireless-Arduino-BSP-Index/main/package_rakwireless.com_rui_index.json
```
After that, you can then add **RAKwireless RUI STM32 Boards** via Arduino board manager.

#### Software

The default firmware of RAK3172_Canopus is based on RUI3, which allows you to develop your own custom firmware to connect sensors and other peripherals to it. To develop using your custom firmware using the Arduino IDE, you need to first add RAKwireless RUI STM32 boards to the Arduino board manager, which will be discussed in this guide. You can then use [RUI3 APIs] (https://docs.rakwireless.com/RUI3/Arduino-API/) for your intended application.

##### RAK3172_Canopus board Support Package in Arduino IDE

If you don't have an Arduino IDE yet, you can download it on the [Arduino official website](https://www.arduino.cc/en/Main/Software) and follow the installation procedure in the [miscellaneous section](/Product-Categories/wisduo/RAK3172-Module/Quickstart/#arduino-installation) of this document.
  
Once the Arduino IDE has been successfully installed, you can now configure the IDE to add the RAK3172_Canopus to its board selection by following these steps.

1. Open Arduino IDE and go to **File** > **Preferences**.

preferences

2. To add the RAK3172_Canopus to your Arduino Boards list, edit the **Additional Board Manager URLs**.

additional-boards

3. Copy the URL below and paste it on the field. If there are other URLs already there, just add them on the next line. After adding the URL, click **OK**.

```json
https://raw.githubusercontent.com/RAKWireless/RAKwireless-Arduino-BSP-Index/main/package_rakwireless.com_rui_index.json
```

preferences-url

4. Restart the Arduino IDE.

5. Open the Boards Manager from the Tools Menu.

boards-manager

6. Write `RAK` in the search bar. This will show the available RAKwireless module boards that you can add to your Arduino Board list.

7. Click on the area highlighted in blue to select **RAKwireless RUI STM32 Boards**. Install the latest version of the  **RAKwireless RUI STM32 Boards** by clicking on **Install** button.

rui3-stm32

##### Configure RAK3172_Canopus on Boards Manager

8. Once the BSP is installed, select  **Tools** > **Boards Manager** > **RAKWireless RUI STM32 Modules** > **WisDuo RAK3172 Evaluation Board**. 

The RAK3172_Canopus board uses the RAK3172 WisDuo module.
rui-stm32

9. Install ArduLora library

The **ArduLora** library is now officially available in the Arduino IDE Library Manager!

1. Open Arduino IDE and go to **Sketch** > **Include Library** > **Manage Libraries...** (or press Ctrl+Shift+I).
2. Search for **ArduLora** in the search bar.  

     

3. Click on the **Install** button to install the latest version.

*(Alternatively, you can still download the library as a .ZIP from this repository and install it via Sketch > Include Library > Add .ZIP Library...)*

**Finding ArduLora Examples:**
Once installed, you can find all the examples under **File > Examples > ArduLora** in the Arduino IDE.

##### RAK3172 COM Port on Device Manager

Connect the RAK3172 via USB type C and check COM Port using Windows **Device Manager**. Double-click the reset button if the module is not detected.

rui-port  
#### At here , you are ready 👌 to execute the sample code for the RAK3172_CANOPUS board  

### Compile an Example with Arduino LED Breathing

1. After completing the steps on adding your RAK3172_Canopus to the Arduino IDE, you can now try to run a simple program to test your setup. You need to add two LEDs to the bare minimum schematic of the RAK3172 module.

<rk-img
  src="/assets/images/wisduo/rak3172-module/quickstart/rak3172_bare_minimum_schematic_led.png"
  width="90%"
  caption="RAK3172 with two LEDs"
/>

2. Launch Arduino IDE and configure WisDuo RAK3172 Evaluation Board on board selection.

3. Connect the RAK3172_Canopus via USB type C.

4. Open the **Tools** Menu and select a COM port. **COM28** is currently used.
select-port

5. You can see the serial monitor icon and click it to connect the COM port.
serial-mon

6. Open **Arduino_Led_Breathing** example code.

led-example

7. Click on the **Verify** icon to check if you have successfully compiled the example code.

verify-code

8. Click the **Upload** icon to send the compiled firmware to your RAK3172 module.

:::tip 📝 NOTE:
RAK3172_Canopus should automatically go to BOOT mode when the firmware is uploaded via Arduino IDE.

If BOOT mode is not initiated, pull to ground the RESET pin twice (or double click the reset button if available) to force BOOT mode.
:::

upload-code

9. If the upload is successful, you will see the **Upgrade Complete** message.

dev-prog

10. After the Device Programmed is completed, you will see that LEDs are blinking.

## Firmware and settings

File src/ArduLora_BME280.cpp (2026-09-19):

#include "ArduLora_BME280.h"

ArduLora_BME280::ArduLora_BME280(uint8_t addr, TwoWire *wire) : _addr(addr), _wire(wire) {
    _temperature = -99.0f;
    _pressure = -99.0f;
    _humidity = -99.0f;
    _t_fine = 0;
}

uint8_t ArduLora_BME280::read8(uint8_t reg) {
    _wire->beginTransmission(_addr);
    _wire->write(reg);
    _wire->endTransmission(false);
    _wire->requestFrom(_addr, (uint8_t)1);
    return _wire->read();
}

void ArduLora_BME280::write8(uint8_t reg, uint8_t val) {
    _wire->beginTransmission(_addr);
    _wire->write(reg);
    _wire->write(val);
    _wire->endTransmission();
}

void ArduLora_BME280::readCalibrationData() {
    _wire->beginTransmission(_addr);
    _wire->write(0x88);
    _wire->endTransmission(false);
    _wire->requestFrom(_addr, (uint8_t)24);

    uint8_t b[24];
    for (int i = 0; i < 24; i++) {
        b[i] = _wire->read();
    }

    dig_T1 = (uint16_t)b[0] | ((uint16_t)b[1] << 8);
    dig_T2 = (int16_t)b[2] | ((int16_t)b[3] << 8);
    dig_T3 = (int16_t)b[4] | ((int16_t)b[5] << 8);

    dig_P1 = (uint16_t)b[6] | ((uint16_t)b[7] << 8);
    dig_P2 = (int16_t)b[8] | ((int16_t)b[9] << 8);
    dig_P3 = (int16_t)b[10] | ((int16_t)b[11] << 8);
    dig_P4 = (int16_t)b[12] | ((int16_t)b[13] << 8);
    dig_P5 = (int16_t)b[14] | ((int16_t)b[15] << 8);
    dig_P6 = (int16_t)b[16] | ((int16_t)b[17] << 8);
    dig_P7 = (int16_t)b[18] | ((int16_t)b[19] << 8);
    dig_P8 = (int16_t)b[20] | ((int16_t)b[21] << 8);
    dig_P9 = (int16_t)b[22] | ((int16_t)b[23] << 8);

    dig_H1 = read8(0xA1);

    _wire->beginTransmission(_addr);
    _wire->write(0xE1);
    _wire->endTransmission(false);
    _wire->requestFrom(_addr, (uint8_t)7);

    uint8_t h[7];
    for (int i = 0; i < 7; i++) {
        h[i] = _wire->read();
    }

    dig_H2 = (int16_t)h[0] | ((int16_t)h[1] << 8);
    dig_H3 = h[2];
    dig_H4 = ((int16_t)h[3] << 4) | (h[4] & 0x0F);
    dig_H5 = ((int16_t)h[5] << 4) | (h[4] >> 4);
    dig_H6 = (int8_t)h[6];
}

bool ArduLora_BME280::begin() {
    uint8_t chip_id = read8(0xD0);
    if (chip_id != 0x60 && chip_id != 0x58) { // 0x60 = BME280, 0x58 = BMP280
        return false;
    }

    readCalibrationData();

    // Humidity oversampling x1
    write8(0xF2, 0x01);
    // Config: standby 500ms, filter 16
    write8(0xF5, 0xA0);
    // ctrl_meas: temp oversampling x1, press oversampling x1, normal mode (0b00100111 = 0x27)
    write8(0xF4, 0x27);

    delay(50);
    return true;
}

bool ArduLora_BME280::measure() {
    _wire->beginTransmission(_addr);
    _wire->write(0xF7);
    if (_wire->endTransmission(false) != 0) return false;

    if (_wire->requestFrom(_addr, (uint8_t)8) != 8) return false;

    uint8_t data[8];
    for (int i = 0; i < 8; i++) {
        data[i] = _wire->read();
    }

    int32_t adc_P = ((uint32_t)data[0] << 12) | ((uint32_t)data[1] << 4) | ((uint32_t)data[2] >> 4);
    int32_t adc_T = ((uint32_t)data[3] << 12) | ((uint32_t)data[4] << 4) | ((uint32_t)data[5] >> 4);
    int32_t adc_H = ((uint32_t)data[6] << 8) | (uint32_t)data[7];

    // Temperature compensation
    int32_t var1 = ((((adc_T >> 3) - ((int32_t)dig_T1 << 1))) * ((int32_t)dig_T2)) >> 11;
    int32_t var2 = (((((adc_T >> 4) - ((int32_t)dig_T1)) * ((adc_T >> 4) - ((int32_t)dig_T1))) >> 12) * ((int32_t)dig_T3)) >> 14;
    _t_fine = var1 + var2;
    _temperature = (_t_fine * 5 + 128) >> 8;
    _temperature /= 100.0f;

    // Pressure compensation
    int64_t p_var1 = ((int64_t)_t_fine) - 128000;
    int64_t p_var2 = p_var1 * p_var1 * (int64_t)dig_P6;
    p_var2 = p_var2 + ((p_var1 * (int64_t)dig_P5) << 17);
    p_var2 = p_var2 + (((int64_t)dig_P4) << 35);
    p_var1 = ((p_var1 * p_var1 * (int64_t)dig_P3) >> 8) + ((p_var1 * (int64_t)dig_P2) << 12);
    p_var1 = (((((int64_t)1) << 47) + p_var1)) * ((int64_t)dig_P1) >> 33;

    if (p_var1 == 0) {
        _pressure = 0.0f;
    } else {
        int64_t p = 1048576 - adc_P;
        p = (((p << 31) - p_var2) * 3125) / p_var1;
        p_var1 = (((int64_t)dig_P9) * (p >> 13) * (p >> 13)) >> 25;
        p_var2 = (((int64_t)dig_P8) * p) >> 19;
        p = ((p + p_var1 + p_var2) >> 8) + (((int64_t)dig_P7) << 4);
        _pressure = (float)p / 256.0f / 100.0f; // in hPa
    }

    // Humidity compensation
    int32_t h_var = (_t_fine - ((int32_t)76800));
    h_var = (((((adc_H << 14) - (((int32_t)dig_H4) << 20) - (((int32_t)dig_H5) * h_var)) +
               ((int32_t)16384)) >> 15) * (((((((h_var * ((int32_t)dig_H6)) >> 10) *
               (((h_var * ((int32_t)dig_H3)) >> 11) + ((int32_t)32768))) >> 10) +
               ((int32_t)2097152)) * ((int32_t)dig_H2) + 8192) >> 14));
    h_var = (h_var - (((((h_var >> 15) * (h_var >> 15)) >> 7) * ((int32_t)dig_H1)) >> 4));
    h_var = (h_var < 0) ? 0 : h_var;
    h_var = (h_var > 419430400) ? 419430400 : h_var;
    _humidity = (float)(h_var >> 12) / 1024.0f;

    return true;
}

float ArduLora_BME280::temperature() {
    return _temperature;
}

float ArduLora_BME280::pressure() {
    return _pressure;
}

float ArduLora_BME280::humidity() {
    return _humidity;
}

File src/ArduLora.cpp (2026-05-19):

#include "ArduLora.h"

ArduLoraClass::ArduLoraClass() {
    // Constructor
}

void ArduLoraClass::begin() {
    // Initialize power control pin
    pinMode(ARDULORA_SENSOR_POWER, OUTPUT);
    digitalWrite(ARDULORA_SENSOR_POWER, HIGH);

    // Initialize LEDs
    pinMode(ARDULORA_LED_YELLOW, OUTPUT);
    pinMode(ARDULORA_LED_RED, OUTPUT);
    pinMode(ARDULORA_LED_BLUE, OUTPUT);

    // Increase ADC resolution for better analog readings
    analogReadResolution(12);
}

void ArduLoraClass::sensorPower(bool state) {
    digitalWrite(ARDULORA_SENSOR_POWER, state ? LOW : HIGH);
}

void ArduLoraClass::setLed(uint8_t ledPin, bool state) {
    digitalWrite(ledPin, state ? HIGH : LOW);
}

float ArduLoraClass::readAI1_mV() {
    // Reading raw value and multiplying by the voltage divider coefficient (approx 2.58)
    return analogRead(ARDULORA_AI1) * 2.58; 
}

float ArduLoraClass::readAI2_mV() {
    return analogRead(ARDULORA_AI2) * 2.58;
}

bool ArduLoraClass::configLoraP2P(double freq, uint16_t sf, uint16_t bw, uint16_t cr, uint16_t preamble, uint16_t txPower) {
    // Switch to P2P mode if currently in LoRaWAN
    if (api.lora.nwm.get() != 0) {
        api.lora.nwm.set(0); 
        api.system.reboot(); // Reboot is required after changing network work mode
    }

    bool success = true;
    success &= api.lora.pfreq.set(freq);
    success &= api.lora.psf.set(sf);
    success &= api.lora.pbw.set(bw);
    success &= api.lora.pcr.set(cr);
    success &= api.lora.ppl.set(preamble);
    success &= api.lora.ptp.set(txPower);

    return success;
}

bool ArduLoraClass::sendP2P(uint8_t *payload, uint16_t len) {
    return api.lora.psend(len, payload);
}

bool ArduLoraClass::configLoRaWAN(uint8_t *devEui, uint8_t *appEui, uint8_t *appKey, uint8_t lorawanClass, uint8_t region) {
    // Switch to LoRaWAN mode if currently in P2P mode
    if (api.lora.nwm.get() != 1) {
        api.lora.nwm.set(1); 
        api.system.reboot(); // Reboot is required after changing network work mode
    }

    bool success = true;
    success &= api.lora.deveui.set(devEui, 8);
    success &= api.lora.appeui.set(appEui, 8);
    success &= api.lora.appkey.set(appKey, 16);
    success &= api.lora.deviceClass.set(lorawanClass);
    success &= api.lora.band.set(region);
    
    return success;
}

bool ArduLoraClass::joinLoRaWAN(uint8_t join_mode) {
    api.lora.njm.set(join_mode); // 1 for OTAA, 0 for ABP
    return api.lora.join();
}

bool ArduLoraClass::sendLoRaWAN(uint8_t port, uint8_t *payload, uint16_t len) {
    return api.lora.send(len, payload, port);
}

void ArduLoraClass::deepSleep(uint32_t time_ms) {
    api.system.sleep.all(time_ms);
}

void ArduLoraClass::reboot() {
    api.system.reboot();
}

String ArduLoraClass::getChipID() {
    return api.system.chipId.get();
}

// Instantiate the global object
ArduLoraClass ArduLora;

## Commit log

2026-04-12 Add RAK3172 LoRaWAN ABP Example sketch demonstrating Activation By Personalization with device address and keys
2026-05-02 Add case box 3D
    [Hop nhua 100x68x50.x_t, Hộp nhựa 100x68x50mm BOT.step, Hộp nhựa 100x68x50mm TOP.step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]
2026-05-03 Update name 3D file
    [BOT.step, Full.step, Hop nhua 100x68x50.x_t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]
2026-05-19 docs/hardware: update pin mapping for new board revision (AI1 to PA10, AI2 to PA15, PB5 sensor power to active-low)
2026-05-19 feat: integrate ArtronShop_SHT3x and ArtronShop_BH1750 drivers into ArduLora library
2026-05-19 refactor: rename sensor drivers to ArduLora brand
2026-09-19 feat: add 8 I2C sensor drivers (BME280, MLX90614, INA219, MPU6050, QMC5883L, VL53L0X, CCS811, APDS9960) and bump to v1.2.0

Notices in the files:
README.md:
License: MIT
